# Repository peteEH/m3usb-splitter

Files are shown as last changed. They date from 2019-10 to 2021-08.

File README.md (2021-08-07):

# m3usb-splitter

tesla model 3 usb splitter

 -- splits a single usb port into a data only port (low power) and a charging power port
 -- option to provide either D+/D- short or a dedicated charging identification chip
 
 -- multiple PCB "variants" included, depends on the flash drive or cables used to attach to the splitter.

Tesla includes charging cables that short D+/D- together - these docking cables when used, properly idenify the usb source as a charging adaptor (USB spec)

Typical use case:

--- Samsung T5 500GB SSD plugs into the data port
--- included tesla charging cable for docking plugs into the power only port

BOM (exact or similar PNs):
(minimal)

2x UE27AC54100  USB Type A Receptacle - Right Angle, Through Hole
1x UP2-AH-1-TH  USB Type A Plug - Right Angle, Through Hole
1x 10uF, 0805, 10V Capacitor
1x 0 Ohm, 0805 Resistor
1x PCB (i.e. JLC or similar - about $2)

(with dedicated charger chip - add these parts)
1x TPS2514A   Dedicated D+/D- charger ID chip
1x 10uF, 0805, 10V Capacitor

m3_splitter_version1
m3_splitter_version2
stacked_bot
stacked_top

## LICENSE ##
Hardware License is Creative Commons - Attribution 3.0

Feel free to use these files to learn, explore electronics.

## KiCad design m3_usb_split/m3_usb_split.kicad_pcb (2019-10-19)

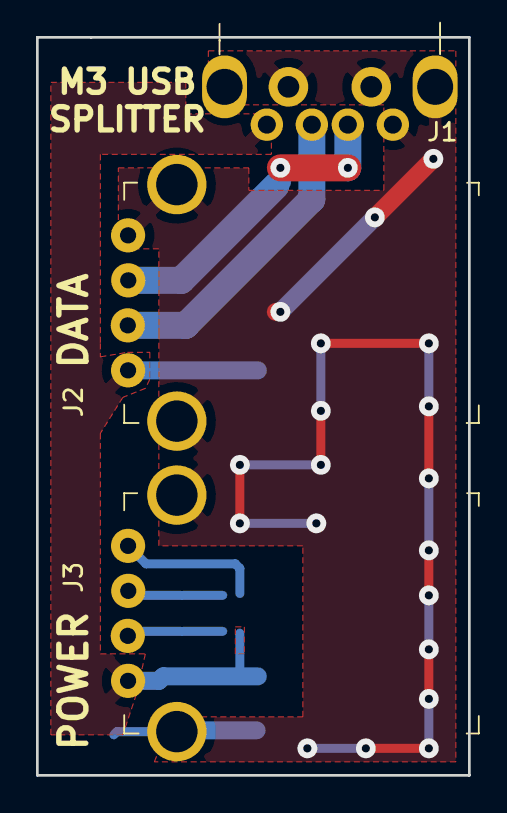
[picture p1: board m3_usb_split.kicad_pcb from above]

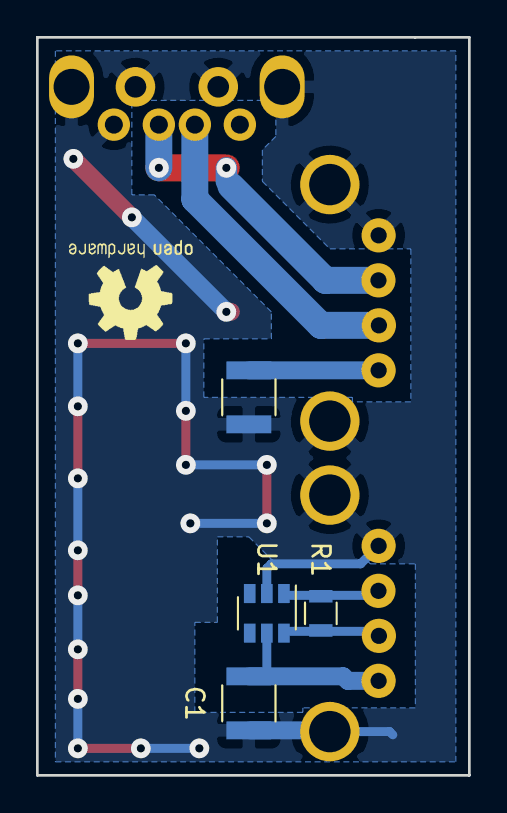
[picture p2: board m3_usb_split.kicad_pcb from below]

Board: 2 copper layers, 24.0 x 41.0 mm, 7 parts (4 on the bottom side), 6 nets.

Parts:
C1, C2: 10uF; C_1210
J1: UP2-AH-1-TH; USB_Male_A_UP2-AH-1-TH
J2, J3: UE27AC54100; USB_A_Female_UE27AC54100
R1: 0R; R_0805
U1: TPS2514A; SOT-23-6

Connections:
GND: C1.2, C2.2, J1.4, J1.5, J2.4, J2.5, J3.4, J3.5, U1.2
unnamed: J1.2, J2.2
unnamed: J1.3, J2.3
unnamed: J3.2, R1.2, U1.6
unnamed: J3.3, R1.1, U1.1
VBUS: C1.1, C2.1, J1.1, J2.1, J3.1, U1.5

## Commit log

2019-10-19 added kicad project directory files
    [SecondPort_m3_usb-B.Cu.gbr, SecondPort_m3_usb-B.Fab.gbr, SecondPort_m3_usb-B.Mask.gbr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]
2019-10-26 added BOM info
